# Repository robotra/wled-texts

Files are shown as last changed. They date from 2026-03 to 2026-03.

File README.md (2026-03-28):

# SMS Matrix Display

An ESP32-based scrolling LED matrix display that shows incoming SMS messages fetched from the Twilio API. Configured entirely through a captive-portal web interface — no code changes needed for setup.

---

## Features

- Scrolls the most recent incoming SMS on a 32×8 NeoPixel matrix
- Remembers and restores the last message and text colour across reboots
- Runtime control via SMS commands (text `!color red`, `!speed 200`, `!help`, etc.)
- Settings page accessible at `http://sms-matrix.local/` (mDNS) — no IP address needed
- Settings page protected by HTTP Basic Auth
- Over-the-air firmware updates (no USB cable needed after first flash)
- DST-aware clock via NTP (`!time` is correct year-round)
- Wi-Fi setup via a captive portal (no hardcoded credentials)
- Displays the device IP address on the matrix after connecting
- Twilio SMS polling every 5 seconds on a dedicated core (smooth scrolling, no hitching)
- Optional sender whitelist (allow only specific phone numbers)
- Credential reset via 3 rapid power cycles

---

## Hardware

| Component | Details |
|---|---|
| Microcontroller | ESP32 (e.g. ESP32 DevKit V1) |
| LED Matrix | 32×8 NeoPixel / WS2812B panel |
| Data pin | GPIO 16 → matrix DIN |
| Power | 5V — use a dedicated supply for the matrix at higher brightness |

### Wiring

```
ESP32 GPIO 16  ──►  Matrix DIN
ESP32 GND      ──►  Matrix GND
5V supply      ──►  Matrix VCC + ESP32 VIN
```

> **Note:** The first LED is at the bottom-right corner; rows snake in a zigzag (serpentine) pattern upward. If text appears garbled or mirrored, adjust `MATRIX_TYPE` in `include/config.h`.

---

## Software Dependencies

Built with [PlatformIO](https://platformio.org/) targeting the `esp32dev` board.

| Library | Version |
|---|---|
| Adafruit NeoMatrix | ^1.3.0 |
| Adafruit GFX Library | ^1.11.9 |
| ArduinoJson | ^7.3.0 |

Dependencies are declared in `platformio.ini` and installed automatically by PlatformIO. `ESPmDNS` and `ArduinoOTA` are part of the ESP32 Arduino core — no extra installation needed.

---

## Building & Flashing

1. Install [VS Code](https://code.visualstudio.com/) and the [PlatformIO extension](https://platformio.org/install/ide?install=vscode).
2. Open this folder in VS Code.
3. Click **Build** (✓) to compile, then **Upload** (→) to flash.
4. Open the Serial Monitor at **115200 baud** to see debug output.

After the first USB flash, subsequent firmware updates can be done [over the air](#ota-updates).

---

## First-Time Setup

1. Power on the device for the first time (no credentials stored). The matrix scrolls `SETUP: SMS-Matrix-Setup`.
2. On your phone or laptop, connect to the Wi-Fi network **`SMS-Matrix-Setup`**.
3. A captive portal should open automatically. If not, browse to `http://192.168.4.1`.
4. Fill in the form:
   - **WiFi SSID / Password** — your home/office network
   - **Twilio Account SID** — found in the [Twilio Console](https://console.twilio.com/)
   - **Twilio Auth Token** — found in the Twilio Console
   - **Twilio Phone Number** — the number that receives SMS, in E.164 format (e.g. `+12025551234`)
   - **Allowed Senders** *(optional)* — one E.164 number per line; leave blank to accept messages from anyone
5. Click **Save & Reboot**. The device reboots, connects to Wi-Fi, and scrolls its IP address.

The portal stays open for **5 minutes**. If it closes before you save, power-cycle the device and try again.

> On subsequent boots the portal is skipped and the device connects directly to Wi-Fi. To re-open the portal, perform a [credential reset](#resetting-credentials).

---

## Settings Page

After the initial setup, credentials can be updated at any time without a factory reset by visiting the settings page in a browser:

```
http://sms-matrix.local/
```

If mDNS doesn't work on your network, use the IP address scrolled on the matrix at boot (also printed to Serial Monitor).

The settings page includes a **Timezone** dropdown that auto-detects your location from the browser. Saving a new timezone takes effect immediately for `!time` — no reboot required.

The page is protected by **HTTP Basic Auth**. Default credentials:

| Field | Default |
|---|---|
| Username | `admin` |
| Password | `sms-matrix` |

Change these by editing `WEB_USERNAME` and `WEB_PASSWORD` in `include/config.h` before flashing.

---

## OTA Updates

After the first USB flash, firmware can be updated over WiFi:

**PlatformIO** — add to `platformio.ini`:
```ini
upload_protocol = espota
upload_port = sms-matrix.local
upload_flags = --auth=sms-matrix
```
Then use the normal **Upload** button.

**Arduino IDE** — the device appears under **Tools → Port** as a network port once it's on the same WiFi network. Select it and upload normally; enter `sms-matrix` as the password when prompted.

Change the OTA password by editing `OTA_PASSWORD` in `include/config.h`.

---

## Resetting Credentials

To clear stored Wi-Fi and Twilio credentials and re-open the config portal:

1. Power the device **off**.
2. Power it **on** — wait for the matrix to light up, then immediately power it **off** again (within 3 seconds).
3. Repeat once more (3 power cycles total).

The matrix will scroll **RESET** and the config portal will open.

---

## Twilio Setup

1. Create a free account at [twilio.com](https://www.twilio.com/).
2. Buy or verify a phone number that can receive SMS.
3. Note your **Account SID** and **Auth Token** from the Twilio Console dashboard.
4. Enter these in the config portal as described above.

The device polls the Twilio REST API every 5 seconds and displays the most recent inbound message. It tracks the message SID so the same message is not displayed twice, and persists the SID to flash so a reboot never replays an already-seen message.

Polling runs on **core 0** via a FreeRTOS task, so HTTP latency never interrupts the scroll animation on **core 1**.

---

## SMS Commands

Any message that begins with `!` is treated as a command and is not displayed on the matrix. Commands are subject to the sender whitelist — only permitted numbers can change display settings.

**Persistence:** `!color` is saved to flash and survives a reboot. `!speed` and `!brightness` apply for the current session only — the display always starts at speed 128 and brightness 40 on power-up.

Send `!help` to scroll a summary of all commands on the display.

### `!color <name>`

Changes the text colour. Supported names:

`red` · `green` · `blue` · `white` · `yellow` · `cyan` · `magenta` · `orange` · `purple` · `pink`

```
!color red
!color cyan
```

### `!color <R> <G> <B>`

Sets a custom colour using three space-separated integers (0–255 each).

```
!color 255 128 0
```

### `!speed <1-255>`

Sets the scroll speed for the current session. Higher values are faster. The value maps to a frame delay of `256 − speed` milliseconds. Resets to speed 128 (128 ms/step) on next power-up.

```
!speed 200     ← fast (56 ms/step)
!speed 50      ← slow (206 ms/step)
```

### `!brightness <0-255>`

Sets the LED brightness for the current session. Resets to 40 on next power-up. Keep low (≤80) when powered from USB.

```
!brightness 50
!brightness 200
```

### `!time`

Displays the current date and time, e.g. `Fri Mar 27 09:41 AM`. Requires a WiFi connection for NTP sync. DST is handled automatically via the POSIX timezone rule in `config.h`. The result is not saved — it won't reappear after a reboot.

```
!time
```

> Set your timezone by editing `TZ_POSIX` in `include/config.h`. Common values:
> - Eastern: `"EST5EDT,M3.2.0,M11.1.0"`
> - Central: `"CST6CDT,M3.2.0,M11.1.0"`
> - Mountain: `"MST7MDT,M3.2.0,M11.1.0"`
> - Pacific: `"PST8PDT,M3.2.0,M11.1.0"`

### `!help`

Scrolls a summary of all available commands for 60 seconds, then automatically reverts to the previous message.

```
!help
```

---

## Configuration Reference

All compile-time settings are in [include/config.h](include/config.h).

| Define | Default | Description |
|---|---|---|
| `CONFIG_AP_SSID` | `SMS-Matrix-Setup` | Name of the setup Wi-Fi network |
| `CONFIG_PORTAL_TIMEOUT_MS` | `300000` (5 min) | How long the portal stays open |
| `LED_PIN` | `16` | GPIO pin connected to matrix DIN |
| `MATRIX_WIDTH` | `32` | Number of LED columns |
| `MATRIX_HEIGHT` | `8` | Number of LED rows |
| `LED_BRIGHTNESS` | `20` | Compile-time brightness default (runtime boot value is fixed at 40) |
| `MATRIX_TYPE` | `BOTTOM + RIGHT + COLUMNS + ZIGZAG` | Matrix wiring orientation |
| `TEXT_COLOR_R/G/B` | `255, 255, 255` | Default scroll text colour (white) |
| `SCROLL_DELAY_MS` | `50` | Compile-time scroll delay (runtime boot value is fixed at 128 ms) |
| `POLL_INTERVAL_MS` | `5000` | Milliseconds between Twilio API polls |
| `NTP_SERVER` | `pool.ntp.org` | NTP server for `!time` |
| `TZ_POSIX` | `EST5EDT,...` | POSIX timezone rule (handles DST automatically) |
| `MDNS_HOSTNAME` | `sms-matrix` | mDNS hostname (`sms-matrix.local`) |
| `WEB_USERNAME` | `admin` | Settings page username |
| `WEB_PASSWORD` | `sms-matrix` | Settings page password |
| `OTA_PASSWORD` | `sms-matrix` | OTA firmware update password |

---

## Troubleshooting

| Symptom | Fix |
|---|---|
| Text is upside-down or mirrored | Adjust `MATRIX_TYPE` in `config.h` (try swapping `TOP`/`BOTTOM`, `LEFT`/`RIGHT`, or `ZIGZAG`/`PROGRESSIVE`) |
| Portal doesn't open automatically | Browse manually to `http://192.168.4.1` while connected to `SMS-Matrix-Setup` |
| Device won't connect to Wi-Fi | Reset credentials (3 power cycles) and re-enter them |
| No messages displayed | Check Twilio credentials and ensure messages are sent **to** the configured number |
| Matrix is too dim / too bright | Send `!brightness <value>` or adjust `LED_BRIGHTNESS` in `config.h` (values above ~80 require a dedicated 5V supply) |
| `!color` / `!speed` command ignored | The sending number must be on the whitelist (or the whitelist must be empty) |
| Display shows old message after reboot | Expected — the last non-command message is restored from flash on every boot |
| `sms-matrix.local` not resolving | Use the IP address shown on the matrix at boot; mDNS can be unreliable on some routers |
| OTA upload fails | Ensure the device is on the same WiFi network and the password in `platformio.ini` matches `OTA_PASSWORD` in `config.h` |
| `!time` shows wrong time | Check `TZ_POSIX` in `config.h` matches your timezone |

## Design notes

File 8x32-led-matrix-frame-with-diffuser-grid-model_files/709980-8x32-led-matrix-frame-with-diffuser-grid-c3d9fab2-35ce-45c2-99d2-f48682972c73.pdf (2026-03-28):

## 8x32 LED Matrix Frame with Diffuser

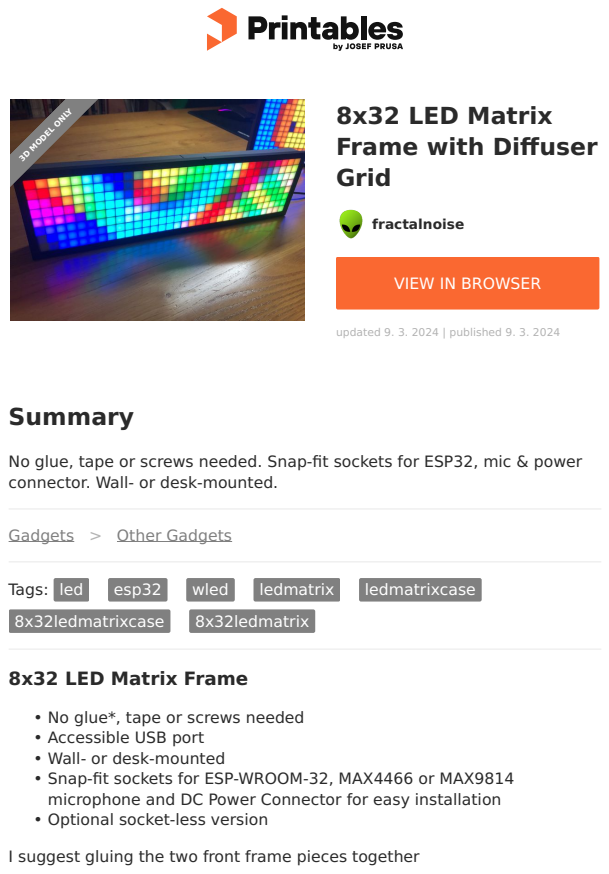
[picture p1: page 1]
Summary; Tags:; led; esp32; wled; ledmatrix; ledmatrixcase; 8x32ledmatrixcase; 8x32ledmatrix; fractalnoise; Grid; updated 9. 3. 2024 | published 9. 3. 2024; 3D MODEL ONLY

VIEW IN BROWSER (https://printables.com/model/709980-8x32-led-matrix-frame-with-diffuser-grid)

No glue, tape or screws needed. Snap-fit sockets for ESP32, mic & power
connector. Wall- or desk-mounted.

Gadgets (https://printables.com/model?categoryId=21) > Other Gadgets (https://printables.com/model?categoryId=43)

8x32 LED Matrix Frame

No glue*, tape or screws needed
Accessible USB port
Wall- or desk-mounted
Snap-fit sockets for ESP-WROOM-32, MAX4466 or MAX9814
microphone and DC Power Connector for easy installation
Optional socket-less version

I suggest gluing the two front frame pieces together

Instructions

Print:

2xFront SPLIT
2xDiffuser SPLIT
1xBackL SPLIT
1xBackR SPLIT

Print the Diffuser Screens with these settings to give the screen a horizontal “scanline” texture:

Top/Bottom surface pattern: ALIGNED RECTILINEAR Internal solid infill pattern: ALIGNED RECTILINEAR
Sparse infill pattern: ALIGNED RECTILINEAR
Infill direction: 0

If using white filament for the Diffuser Screen, printing it on a textured plate will make it scatter more light and be dimmer. Use a smooth plate for best results. A textured plate will work great for clear filament though :)

For the LED matrix, you'll need:

8x32 LED Matrix - e.g. https://aliexpress.com/item/4000544411175.html (https://aliexpress.com/item/4000544411175.html)
ESP-Wroom-32 - e.g. https://aliexpress.com/item/1005005972312714.html (https://aliexpress.com/item/1005005972312714.html)
MAX4466 microphone - e.g. https://aliexpress.com/item/3256803608057399.html (https://aliexpress.com/item/3256803608057399.html)
or
MAX9814 microphone - e.g. https://aliexpress.com/item/3256805923391884.html (https://aliexpress.com/item/3256805923391884.html)
Power Supply 5V 1.5A-15A (~2-5A will do for most uses) - e.g. https://aliexpress.com/item/32844702891.html or https://aliexpress.com/item/1005006126703620.html (https://aliexpress.com/item/1005006126703620.html)
or an old USB cable (cut one end and connect the + and - to the LED matrix)

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
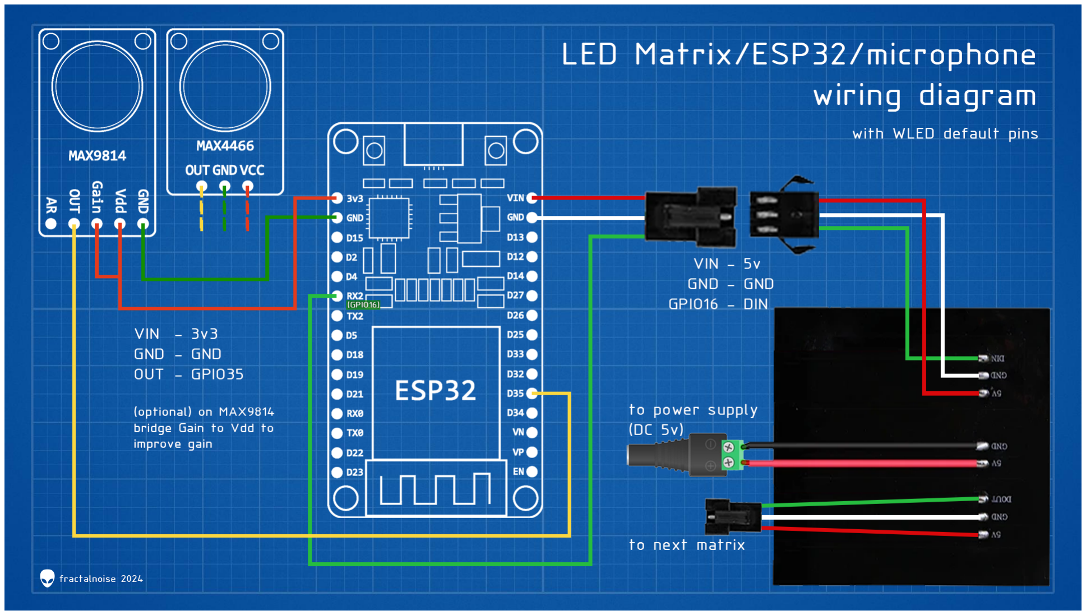
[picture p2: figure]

## Model files

LED Matrix/ESP32/WLED Assembly Guide:

Some useful resources:

WLED Project: https://kno.wled.ge/
Chris Maher WLED tutorials playlist: https://www.youtube.com/playlist?list=PLur8dX5PE-4pk838s_gZAdm-98-sf0f0Z (https://www.youtube.com/playlist?list=PLur8dX5PE-4pk838s_gZAdm-98-sf0f0Z)
Make It Work WLED tutorials playlist: https://www.youtube.com/playlist?list=PLUTKOGJvdIQ8WYfG6TDJ_c8_WlPovWbL9 (https://www.youtube.com/playlist?list=PLUTKOGJvdIQ8WYfG6TDJ_c8_WlPovWbL9)

My other LED projects:

https://www.printables.com/@fractalnoise/collections/1236469

- SPLIT - 3mf | 5 files

•
•

•

8x32-led-matrix-frame-front-split.3mf

- SPLIT - stl | 7 files

8x32-led-matrix-frame-diffuser-split.3mf

8x32-led-matrix-frame-backl-split.3mf

8x32-led-matrix-frame-backl-no-sockets-split.3mf

8x32-led-matrix-frame-backr-split.3mf

8x32-led-matrix-frame-front-split.stl

8x32-led-matrix-frame-diffuser-split.stl

8x32-led-matrix-frame-diffuser_screen-split.stl

8x32-led-matrix-frame-diffuser_grid-split.stl

- WHOLE - 3mf | 4 files
- WHOLE - stl | 6 files

8x32-led-matrix-frame-backl-split.stl

8x32-led-matrix-frame-backl-no-sockets-split.stl

8x32-led-matrix-frame-backr-split.stl

8x32-led-matrix-frame-front-whole.3mf

8x32-led-matrix-frame-diffuser-whole.3mf

8x32-led-matrix-frame-back-whole.3mf

8x32-led-matrix-frame-back-no-sockets-whole.3mf

## License

This work is licensed under a
Creative Commons (4.0 International License)

Attribution—Noncommercial—Share Alike (http://creativecommons.org/licenses/by-nc-sa/4.0/)

✖ | Sharing without ATTRIBUTION
✔ | Remix Culture allowed

8x32-led-matrix-frame-front-whole.stl

8x32-led-matrix-frame-diffuser-whole.stl

8x32-led-matrix-frame-diffuser_screen-whole.stl

8x32-led-matrix-frame-diffuser_grid-whole.stl

8x32-led-matrix-frame-back-whole.stl

8x32-led-matrix-frame-back-no-sockets-whole.stl

8x32-led-matrix-frame.step

✖ | Commercial Use
✖ | Free Cultural Works
✖ | Meets Open Definition

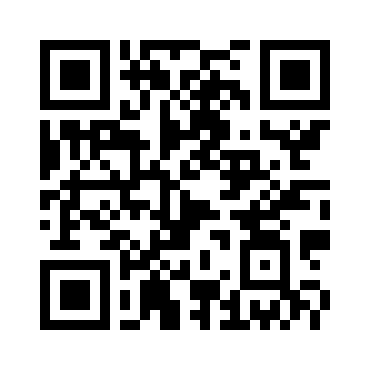
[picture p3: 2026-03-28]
wifi_qr.png

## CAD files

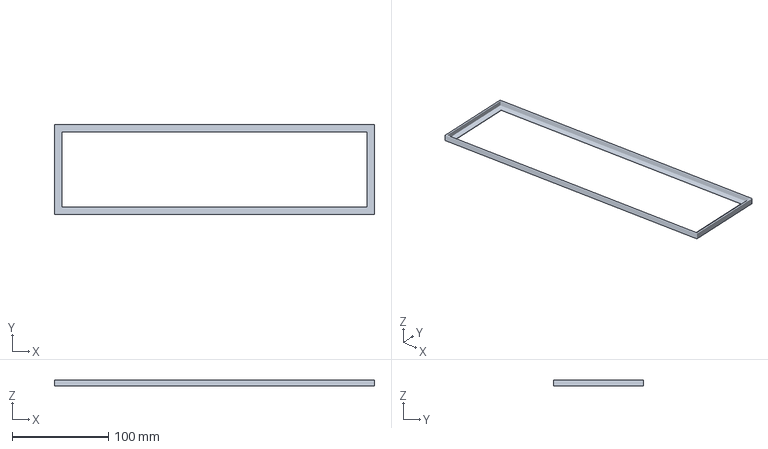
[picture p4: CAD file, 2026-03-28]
8x32-led-matrix-frame-with-diffuser-grid-model_files/WHOLE - 3mf/8x32-led-matrix-frame-front-whole.3mf
333.2 x 93.2 x 6.20 mm

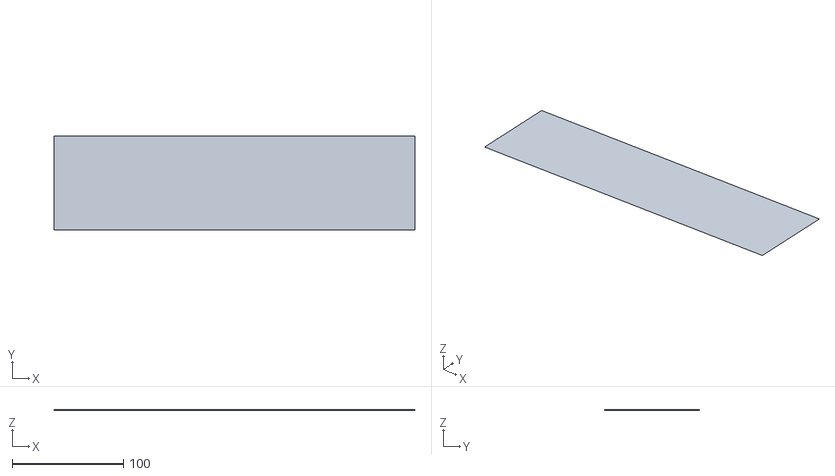
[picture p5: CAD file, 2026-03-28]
8x32-led-matrix-frame-with-diffuser-grid-model_files/WHOLE - stl/8x32-led-matrix-frame-diffuser_screen-whole.stl
325.0 x 85.0 x 0.45

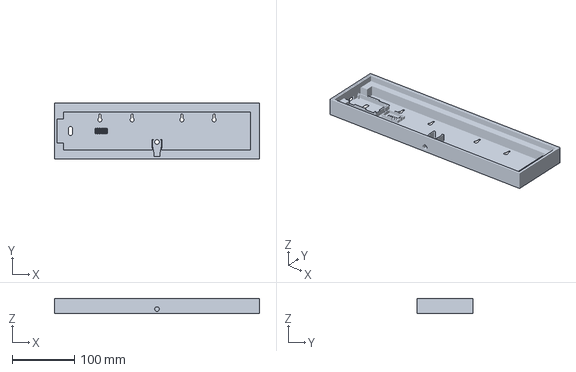
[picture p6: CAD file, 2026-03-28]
8x32-led-matrix-frame-with-diffuser-grid-model_files/WHOLE - 3mf/8x32-led-matrix-frame-back-whole.3mf
330.0 x 90.0 x 24.0 mm

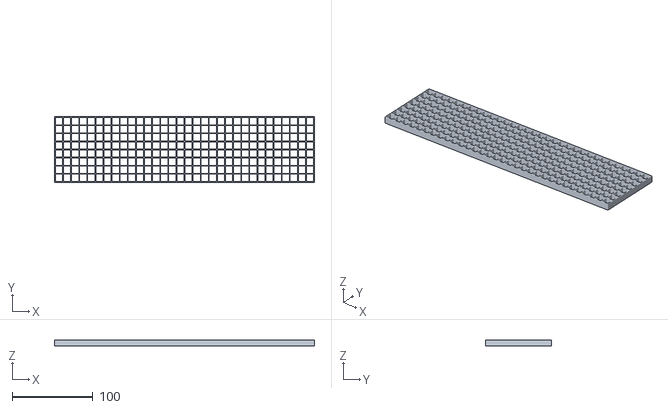
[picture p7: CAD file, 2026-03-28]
8x32-led-matrix-frame-with-diffuser-grid-model_files/WHOLE - stl/8x32-led-matrix-frame-diffuser_grid-whole.stl
321.0 x 81.0 x 8.00

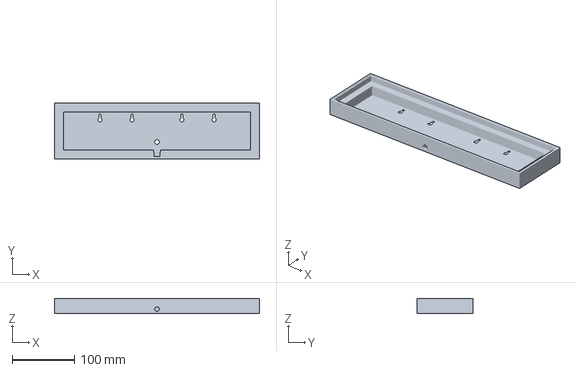
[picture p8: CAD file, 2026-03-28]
8x32-led-matrix-frame-with-diffuser-grid-model_files/WHOLE - 3mf/8x32-led-matrix-frame-back-no-sockets-whole.3mf
330.0 x 90.0 x 24.0 mm

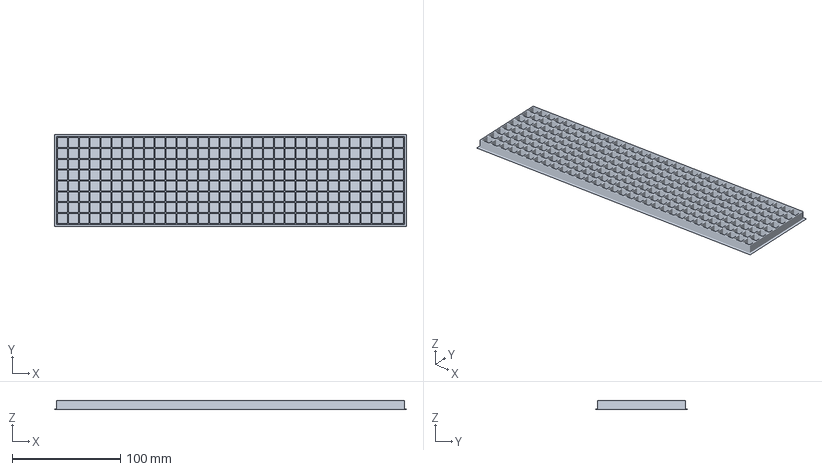
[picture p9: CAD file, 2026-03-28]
8x32-led-matrix-frame-with-diffuser-grid-model_files/WHOLE - 3mf/8x32-led-matrix-frame-diffuser-whole.3mf
325.0 x 85.0 x 8.45 mm

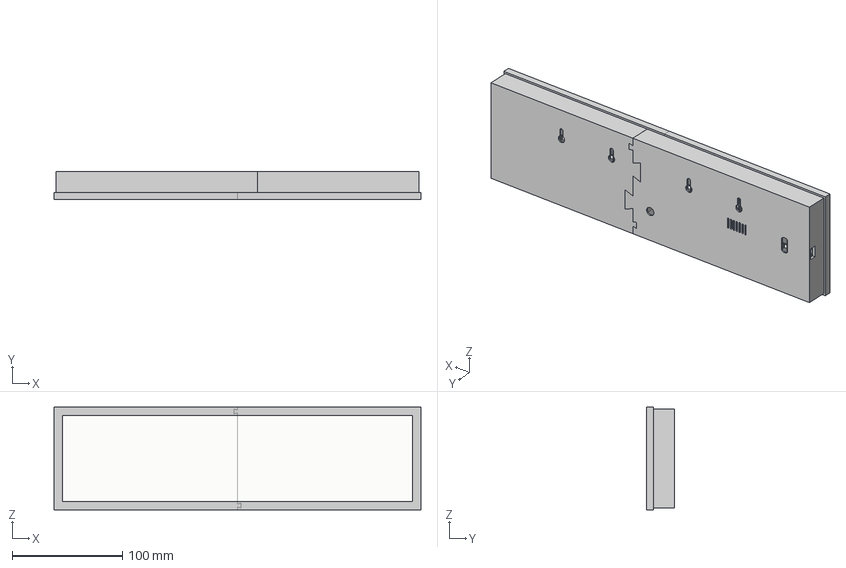
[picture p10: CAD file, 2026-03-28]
8x32-led-matrix-frame-with-diffuser-grid-model_files/8x32-led-matrix-frame.step
333.2 x 25.2 x 93.2 mm
Diffuser
Back
Front

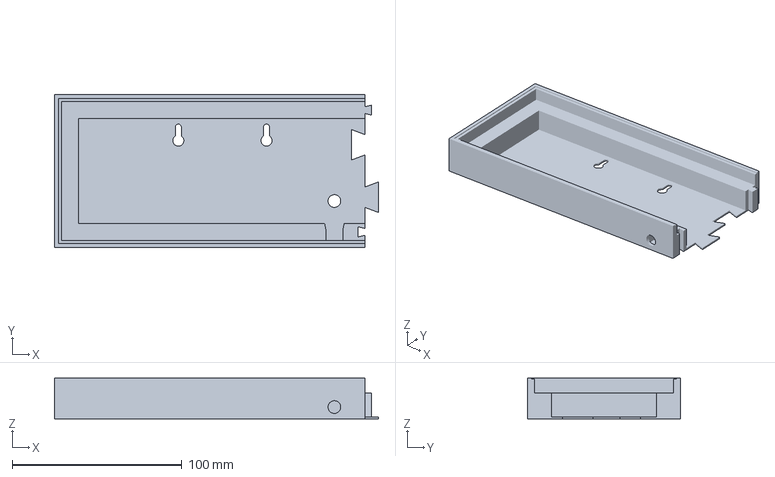
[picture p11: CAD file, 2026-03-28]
8x32-led-matrix-frame-with-diffuser-grid-model_files/SPLIT - 3mf/8x32-led-matrix-frame-backl-no-sockets-split.3mf
191.0 x 90.0 x 24.0 mm

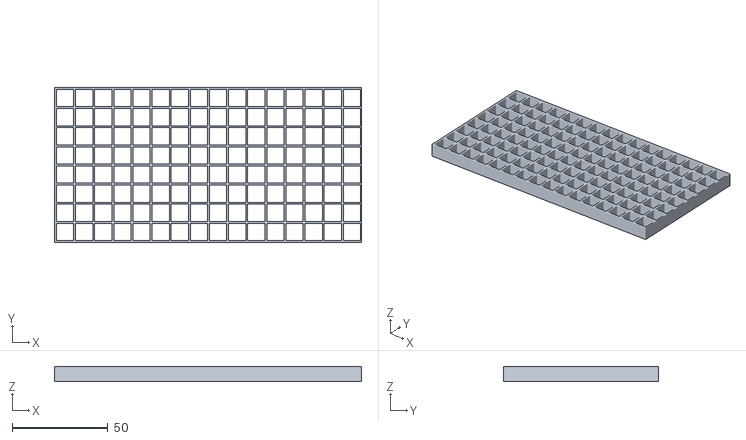
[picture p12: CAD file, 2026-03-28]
8x32-led-matrix-frame-with-diffuser-grid-model_files/SPLIT - stl/8x32-led-matrix-frame-diffuser_grid-split.stl
160.5 x 81.0 x 8.00

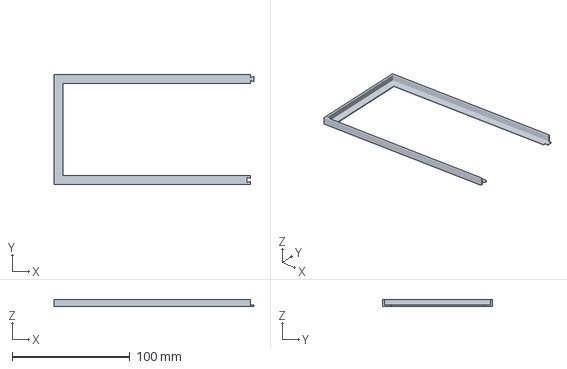
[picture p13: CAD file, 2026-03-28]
8x32-led-matrix-frame-with-diffuser-grid-model_files/SPLIT - 3mf/8x32-led-matrix-frame-front-split.3mf
169.6 x 93.2 x 6.20 mm

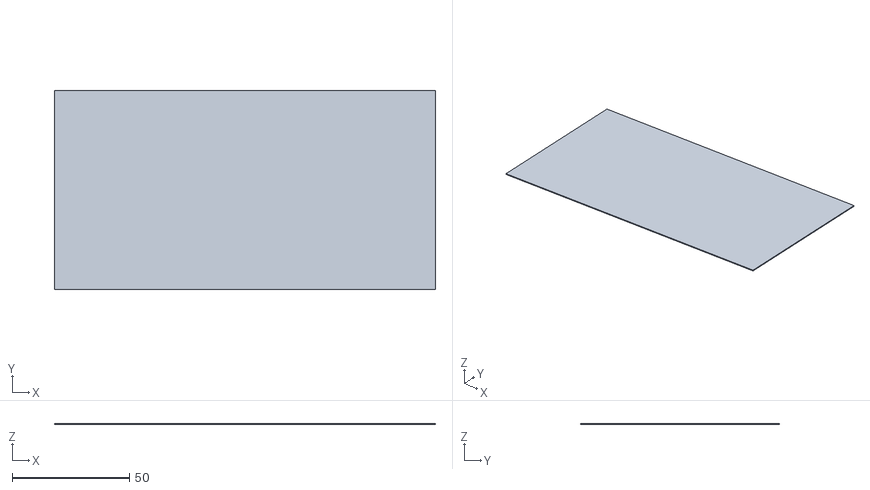
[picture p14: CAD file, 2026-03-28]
8x32-led-matrix-frame-with-diffuser-grid-model_files/SPLIT - stl/8x32-led-matrix-frame-diffuser_screen-split.stl
162.5 x 85.0 x 0.45

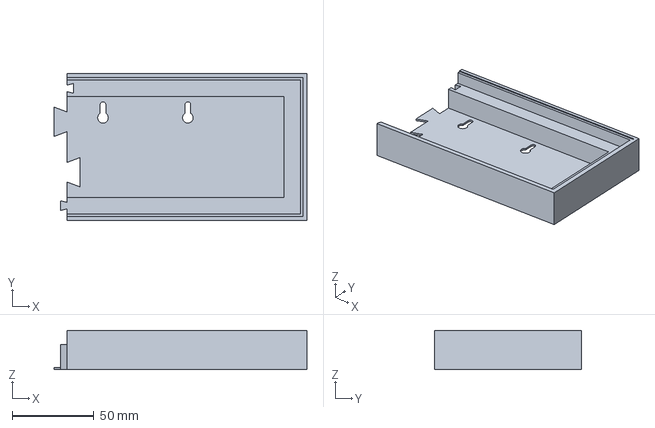
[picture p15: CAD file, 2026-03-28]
8x32-led-matrix-frame-with-diffuser-grid-model_files/SPLIT - 3mf/8x32-led-matrix-frame-backr-split.3mf
155.0 x 90.0 x 24.0 mm

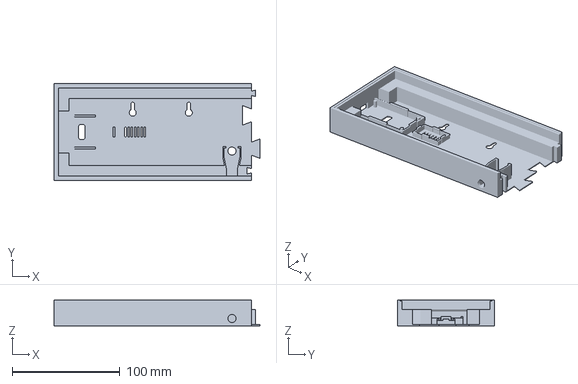
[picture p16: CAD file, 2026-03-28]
8x32-led-matrix-frame-with-diffuser-grid-model_files/SPLIT - 3mf/8x32-led-matrix-frame-backl-split.3mf
191.0 x 90.0 x 24.0 mm

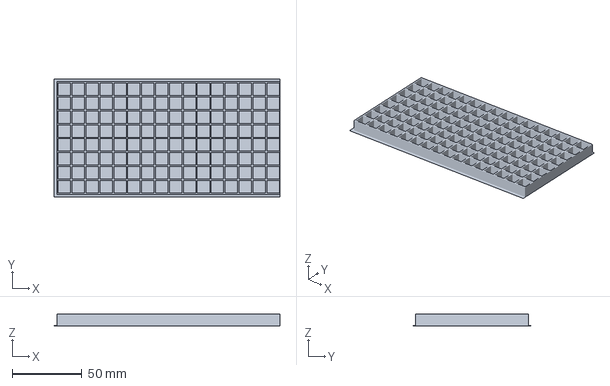
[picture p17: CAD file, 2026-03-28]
8x32-led-matrix-frame-with-diffuser-grid-model_files/SPLIT - 3mf/8x32-led-matrix-frame-diffuser-split.3mf
162.5 x 85.0 x 8.45 mm

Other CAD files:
8x32-led-matrix-frame-with-diffuser-grid-model_files/SPLIT - stl/8x32-led-matrix-frame-backl-no-sockets-split.stl
8x32-led-matrix-frame-with-diffuser-grid-model_files/SPLIT - stl/8x32-led-matrix-frame-backl-split.stl
8x32-led-matrix-frame-with-diffuser-grid-model_files/SPLIT - stl/8x32-led-matrix-frame-backr-split.stl
8x32-led-matrix-frame-with-diffuser-grid-model_files/SPLIT - stl/8x32-led-matrix-frame-diffuser-split.stl
8x32-led-matrix-frame-with-diffuser-grid-model_files/SPLIT - stl/8x32-led-matrix-frame-front-split.stl
8x32-led-matrix-frame-with-diffuser-grid-model_files/WHOLE - stl/8x32-led-matrix-frame-back-no-sockets-whole.stl
8x32-led-matrix-frame-with-diffuser-grid-model_files/WHOLE - stl/8x32-led-matrix-frame-back-whole.stl
8x32-led-matrix-frame-with-diffuser-grid-model_files/WHOLE - stl/8x32-led-matrix-frame-diffuser-whole.stl
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

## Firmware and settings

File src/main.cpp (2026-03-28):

// =============================================================================
//  SMS Matrix — main.cpp
//
//  Scrolls the most-recent inbound Twilio SMS across an 8×32 NeoPixel matrix.
//
//  Boot flow
//  ---------
//  1. Power on → matrix initialised, NVS opened.
//  2. If the device has been power-cycled 3 times in quick succession the NVS
//     is wiped and the config portal opens so the user can re-enter credentials.
//  3. If no WiFi SSID is stored the config portal opens automatically.
//  4. Config is loaded from NVS, the device connects to WiFi in station mode.
//  5. NTP sync begins; timezone (POSIX string) is loaded from NVS so DST is
//     handled automatically for !time.
//  6. Settings web server starts on port 80 (HTTP Basic Auth protected).
//     mDNS advertises the device as http://sms-matrix.local/.
//  7. ArduinoOTA is started so firmware can be updated over WiFi.
//  8. A background FreeRTOS task (core 0) polls the Twilio REST API every
//     POLL_INTERVAL_MS milliseconds.
//  9. loop() runs on core 1, servicing OTA, the web server, pending display
//     changes, the !help expiry timer, and the scroll animation.
//
//  Inter-task synchronisation
//  --------------------------
//  The poll task and loop() share `pendingMessage` / `hasPendingMessage`.
//  `msgMutex` ensures the loop() never reads a partially-written string.
// =============================================================================

#include <Arduino.h>
#include <WiFi.h>              // WiFi station + soft-AP
#include <WebServer.h>         // Tiny HTTP server used by the config portal
#include <HTTPClient.h>        // Outbound HTTP(S) requests to Twilio
#include <WiFiClientSecure.h>  // TLS-capable TCP socket (used with HTTPClient)
#include <Preferences.h>       // Arduino wrapper around ESP32 NVS (flash KV store)
#include <ArduinoJson.h>       // Deserialises the Twilio JSON response
#include <Adafruit_NeoMatrix.h>// High-level text/graphics on NeoPixel matrices
#include <Adafruit_GFX.h>      // Base graphics library required by NeoMatrix
#include <ESPmDNS.h>           // mDNS — advertises the device as sms-matrix.local
#include <ArduinoOTA.h>        // Over-the-air firmware updates over WiFi
#include "config.h"            // Hardware pin / timing constants (no secrets)

// =============================================================================
//  Matrix object
//  The constructor arguments describe the physical layout; change MATRIX_TYPE
//  in config.h if the text appears mirrored, upside-down, or in the wrong order.
// =============================================================================
Adafruit_NeoMatrix matrix(
    MATRIX_WIDTH,   // number of pixels across
    MATRIX_HEIGHT,  // number of pixels tall
    LED_PIN,        // GPIO connected to the data-in pin of the first pixel
    MATRIX_TYPE,    // wiring topology (progressive / zigzag, origin corner, etc.)
    NEO_GRB + NEO_KHZ800  // colour order and signal frequency — standard WS2812B
);

// =============================================================================
//  Runtime config — loaded from NVS at boot via loadConfig().
//  Never hard-code credentials here; they are entered through the web portal.
// =============================================================================
struct Config {
    String ssid;          // WiFi network name
    String pass;          // WiFi password (may be empty for open networks)
    String twilioSid;     // Twilio Account SID  (starts with "AC…")
    String twilioToken;   // Twilio Auth Token
    String twilioNumber;  // E.164 number that receives SMS (e.g. "+15550001234")
    String whitelist;     // Newline-separated E.164 senders; empty = allow all
};

Config      cfg;          // Global config populated by loadConfig()
Preferences prefs;        // NVS handle — kept open for the lifetime of the sketch
WebServer   server(80);   // HTTP server instance used only during the config portal

// =============================================================================
//  Scrolling state
//  All access to these from loop() only — no locking needed.
// =============================================================================

// The text currently being scrolled across the matrix.
String currentMessage = "Waiting for SMS...";

// Twilio message SID of the last message we displayed.
// Used to detect when a genuinely new message has arrived.
String lastSeenSid = "";

// Horizontal cursor position for the scroll animation.
// Starts at MATRIX_WIDTH (just off the right edge) and decrements each tick.
int scrollX = MATRIX_WIDTH;

// Timestamp (millis()) of the last scroll step — used for non-blocking timing.
unsigned long lastScrollTime = 0;

// When non-zero, millis() timestamp at which to revert from the !help text back
// to the previous message.  Set by !help, checked in loop().
unsigned long helpExpiresAt  = 0;
String        preHelpMessage = "";  // Message to restore when help expires

// =============================================================================
//  Inter-task message handoff (poll task → loop)
//
//  The poll task writes pendingMessage + sets hasPendingMessage = true while
//  holding msgMutex.  loop() picks it up with a non-blocking tryTake so it
//  never stalls the animation.
// =============================================================================
SemaphoreHandle_t msgMutex;                    // Binary mutex protecting the fields below
String            pendingMessage    = "";       // Latest SMS body from the poll task
volatile bool     hasPendingMessage = false;   // Written core 0, read core 1 — must be volatile

// Pending colour change (written by poll task, applied by loop() via matrix.setTextColor)
volatile bool hasPendingColor = false;         // Written core 0, read core 1 — must be volatile
uint8_t pendingColorR   = TEXT_COLOR_R;
uint8_t pendingColorG   = TEXT_COLOR_G;
uint8_t pendingColorB   = TEXT_COLOR_B;

// Pending scroll-speed change.  Speed 1–255: higher = faster.
// Stored internally as a delay (ms): delay = 256 - speed.
// Reset to 128 ms on every boot regardless of last !speed command.
volatile bool hasPendingSpeed    = false;      // Written core 0, read core 1 — must be volatile
unsigned long pendingScrollDelay = 128;
unsigned long currentScrollDelay = 128;        // Active delay used by loop(); fixed at boot

// Pending brightness change.
// Reset to 40 on every boot regardless of last !brightness command.
volatile bool hasPendingBrightness = false;    // Written core 0, read core 1 — must be volatile
uint8_t       pendingBrightness    = 40;

// =============================================================================
//  Config portal HTML
//
//  Stored in flash (PROGMEM) rather than SRAM to save precious heap space.
//  Placeholder tokens ({{SSID}}, etc.) are replaced at request time with
//  the current NVS values so the form is pre-filled on revisits.
//
//  The countdown script in the page mirrors CONFIG_PORTAL_TIMEOUT_MS (300 s).
// =============================================================================
static const char CONFIG_HTML[] PROGMEM = R"rawliteral(
<!DOCTYPE html><html>
<head>
  <title>SMS Matrix Setup</title>
  <meta name="viewport" content="width=device-width,initial-scale=1">
  <style>
    *{box-sizing:border-box}
    body{font-family:sans-serif;max-width:420px;margin:30px auto;padding:0 16px;background:#111;color:#eee}
    h1{color:#4fc3f7;margin-bottom:4px}
    p{color:#888;font-size:13px;margin-top:0}
    label{display:block;font-size:13px;margin:12px 0 4px;color:#aaa}
    input,textarea,select{width:100%;padding:9px 10px;border:1px solid #333;background:#222;color:#eee;border-radius:4px;font-size:14px}
    input:focus,textarea:focus,select:focus{border-color:#4fc3f7;outline:none}
    textarea{height:90px;resize:vertical;font-family:monospace}
    button{margin-top:20px;width:100%;padding:12px;background:#4fc3f7;color:#111;border:none;border-radius:4px;font-size:15px;font-weight:bold;cursor:pointer}
    .note{color:#f57c00;font-size:13px;margin-top:14px;text-align:center}
  </style>
</head>
<body>
  <h1>SMS Matrix Setup</h1>
  <p>Connect to <b>SMS-Matrix-Setup</b>, fill in the form, and save before the 5-minute window closes.</p>
  <form method="POST" action="/save">
    <label>WiFi SSID</label>
    <input name="ssid" type="text" value="{{SSID}}" required autocomplete="off">
    <label>WiFi Password</label>
    <input name="pass" type="password" value="{{PASS}}" autocomplete="off">
    <label>Twilio Account SID</label>
    <input name="sid" type="text" value="{{SID}}" required autocomplete="off" placeholder="ACxxxxxxxxxxxxxxxxxxxxxxxxxxxxxxxx">
    <label>Twilio Auth Token</label>
    <input name="token" type="password" value="{{TOKEN}}" required autocomplete="off">
    <label>Twilio Phone Number</label>
    <input name="number" type="tel" value="{{NUMBER}}" required placeholder="+1xxxxxxxxxx">
    <label>Allowed Senders (one number per line, E.164 format)</label>
    <textarea name="whitelist" placeholder="+12025551234&#10;+14155559876&#10;&#10;Leave empty to allow everyone.">{{WHITELIST}}</textarea>
    <label>Timezone</label>
    <select name="tz" id="tzsel">
      <option value="EST5EDT,M3.2.0,M11.1.0">Eastern (EST/EDT)</option>
      <option value="CST6CDT,M3.2.0,M11.1.0">Central (CST/CDT)</option>
      <option value="MST7MDT,M3.2.0,M11.1.0">Mountain (MST/MDT)</option>
      <option value="MST7">Mountain – Arizona (no DST)</option>
      <option value="PST8PDT,M3.2.0,M11.1.0">Pacific (PST/PDT)</option>
      <option value="AKST9AKDT,M3.2.0,M11.1.0">Alaska (AKST/AKDT)</option>
      <option value="HST10">Hawaii (HST)</option>
      <option value="UTC0">UTC</option>
    </select>
    <button type="submit">Save &amp; Reboot</button>
  </form>
  <div class="note">Portal closes in <span id="t">300</span>s</div>
  <script>
    var s=300,iv=setInterval(function(){document.getElementById('t').textContent=--s;if(s<=0)clearInterval(iv)},1000);
    // Pre-select stored timezone, or auto-detect from browser if none stored
    (function(){
      var stored="{{TZ}}";
      var ianaMap={
        'America/New_York':'EST5EDT,M3.2.0,M11.1.0',
        'America/Detroit':'EST5EDT,M3.2.0,M11.1.0',
        'America/Indiana/Indianapolis':'EST5EDT,M3.2.0,M11.1.0',
        'America/Chicago':'CST6CDT,M3.2.0,M11.1.0',
        'America/Denver':'MST7MDT,M3.2.0,M11.1.0',
        'America/Phoenix':'MST7',
        'America/Los_Angeles':'PST8PDT,M3.2.0,M11.1.0',
        'America/Anchorage':'AKST9AKDT,M3.2.0,M11.1.0',
        'Pacific/Honolulu':'HST10'
      };
      var val=stored||ianaMap[Intl.DateTimeFormat().resolvedOptions().timeZone]||'';
      var sel=document.getElementById('tzsel');
      for(var i=0;i<sel.options.length;i++){
        if(sel.options[i].value===val){sel.selectedIndex=i;break;}
      }
    })();
  </script>
</body></html>
)rawliteral";

// =============================================================================
//  requireAuth()
//
//  Checks HTTP Basic Auth credentials against WEB_USERNAME / WEB_PASSWORD from
//  config.h.  Call at the top of any handler that should be protected.
//  Returns true if authenticated; false if a 401 challenge was sent (the caller
//  must return immediately without sending another response).
// =============================================================================
bool requireAuth() {
    if (!server.authenticate(WEB_USERNAME, WEB_PASSWORD)) {
        server.requestAuthentication(BASIC_AUTH, "SMS Matrix");
        return false;
    }
    return true;
}

// =============================================================================
//  handleRoot()
//
//  Serves the setup form at GET /.
//  Reads the current NVS values so the form is pre-filled — except passwords,
//  which are intentionally left blank for security.
// =============================================================================
void handleRoot() {
    if (!requireAuth()) return;

    // Copy HTML from flash to a RAM String so we can do replacements on it
    String html = FPSTR(CONFIG_HTML);

    // Substitute each placeholder with the matching stored value.
    // Passwords are shown as empty strings — the user must re-enter them.
    html.replace("{{SSID}}",      prefs.getString("ssid",      ""));
    html.replace("{{PASS}}",      prefs.getString("pass",      ""));  // intentionally blank
    html.replace("{{SID}}",       prefs.getString("tw_sid",    ""));
    html.replace("{{TOKEN}}",     prefs.getString("tw_token",  ""));  // intentionally blank
    html.replace("{{NUMBER}}",    prefs.getString("tw_num",    ""));
    html.replace("{{WHITELIST}}", prefs.getString("whitelist", ""));
    html.replace("{{TZ}}",        prefs.getString("tz_posix",  ""));

    server.send(200, "text/html", html);
}

// =============================================================================
//  handleSave()
//
//  Receives the POST from the setup form, persists each field to NVS, sends an
//  acknowledgment page, then restarts the ESP32 so it boots into normal mode.
//
//  The whitelist is normalised: Windows-style CRLF line endings are converted
//  to LF, and leading/trailing whitespace is stripped before storing.
// =============================================================================
void handleSave() {
    if (!requireAuth()) return;

    // Persist each submitted field; hasArg guards against missing form fields.
    if (server.hasArg("ssid"))   prefs.putString("ssid",     server.arg("ssid"));
    if (server.hasArg("pass"))   prefs.putString("pass",     server.arg("pass"));
    if (server.hasArg("sid"))    prefs.putString("tw_sid",   server.arg("sid"));
    if (server.hasArg("token"))  prefs.putString("tw_token", server.arg("token"));
    if (server.hasArg("number")) prefs.putString("tw_num",   server.arg("number"));
    if (server.hasArg("tz")) {
        String tz = server.arg("tz");
        prefs.putString("tz_posix", tz);
        // Apply immediately so !time reflects the new zone without waiting for reboot
        setenv("TZ", tz.c_str(), 1);
        tzset();
    }

    if (server.hasArg("whitelist")) {
        String wl = server.arg("whitelist");
        // Normalise line endings so the whitelist looks the same regardless of
        // which OS the user's browser is running on.
        wl.replace("\r\n", "\n");  // Windows CRLF → LF
        wl.replace("\r", "\n");    // Old Mac CR  → LF
        wl.trim();                  // Remove surrounding blank lines / spaces
        prefs.putString("whitelist", wl);
    }

    // Acknowledge the save before restarting so the browser receives the reply.
    server.send(200, "text/html",
        "<html><body style='background:#111;color:#4fc3f7;font-family:sans-serif;"
        "padding:40px;text-align:center'><h2>Saved! Rebooting...</h2></body></html>");

    delay(1500);      // Give the browser time to render the response
    ESP.restart();    // Full reset; device will boot into normal (non-portal) mode
}

// =============================================================================
//  handleRedirect()
//
//  Catches the automatic "captive portal detection" probes that Android and iOS
//  send when joining an unknown WiFi network and redirects them to the setup
//  page.  Without this, phones may show "No internet — tap to sign in" but then
//  fail to open the portal automatically.
//
//  Known probe URLs:
//    Android : GET /generate_204
//    iOS/macOS: GET /hotspot-detect.html
// =============================================================================
void handleRedirect() {
    server.sendHeader("Location", "http://192.168.4.1/", true);  // absolute URL required
    server.send(302, "text/plain", "");
}

// =============================================================================
//  runConfigPortal()
//
//  Brings up a WiFi soft-AP and serves the setup form until the user submits
//  valid credentials or until CONFIG_PORTAL_TIMEOUT_MS elapses.
//
//  The matrix keeps scrolling while the portal runs so the user can see the
//  AP name and knows the device is waiting.  handleSave() calls ESP.restart()
//  on success, so this function only returns on timeout.
// =============================================================================
void runConfigPortal() {
    // Show the AP name on the matrix so the user knows what to connect to
    currentMessage = String("SETUP: ") + CONFIG_AP_SSID;
    scrollX = MATRIX_WIDTH;  // Reset scroll so the message starts from the right

    // Bring up the soft-AP.  No password = open network, easier for first setup.
    WiFi.mode(WIFI_AP);
    WiFi.softAP(CONFIG_AP_SSID);
    Serial.println("Config AP started. Connect to: " + String(CONFIG_AP_SSID));
    Serial.println("Portal URL: http://" + WiFi.softAPIP().toString() + "/");

    // Register URL routes
    server.on("/",                    HTTP_GET,  handleRoot);
    server.on("/save",                HTTP_POST, handleSave);
    server.on("/generate_204",        HTTP_GET,  handleRedirect);  // Android captive probe
    server.on("/hotspot-detect.html", HTTP_GET,  handleRedirect);  // iOS captive probe
    server.onNotFound(handleRedirect);  // Catch all other URLs → redirect to portal
    server.begin();

    unsigned long portalStart = millis();

    // Service loop — runs until the portal times out (handleSave restarts early)
    while (millis() - portalStart < CONFIG_PORTAL_TIMEOUT_MS) {
        server.handleClient();  // Process any pending HTTP request

        // Non-blocking scroll animation — identical logic to the normal loop()
        unsigned long now = millis();
        if (now - lastScrollTime >= SCROLL_DELAY_MS) {
            lastScrollTime = now;

            matrix.fillScreen(0);            // Clear all pixels
            matrix.setCursor(scrollX, 1);    // Y=1 centres 7px-tall text in 8 rows
            matrix.print(currentMessage);
            matrix.show();                   // Push pixel data to the strip

            scrollX--;
            // Each character is 6 px wide (5 px glyph + 1 px gap)
            int textPixelWidth = (int)currentMessage.length() * 6;
            // Once the text has fully scrolled off the left edge, reset to the right
            if (scrollX < -textPixelWidth) scrollX = MATRIX_WIDTH;
        }
    }

    // Timeout reached — clean up and return so the caller can decide what to do
    server.stop();
    WiFi.softAPdisconnect(true);  // true = also disable the radio
    Serial.println("Config portal closed, resuming normal boot.");
}

// =============================================================================
//  loadConfig()
//
//  Reads all credential fields from NVS into the global `cfg` struct.
//  Called once after the config portal check in setup().
//  Empty strings are the default so missing keys fail gracefully.
// =============================================================================
void loadConfig() {
    cfg.ssid         = prefs.getString("ssid",      "");
    cfg.pass         = prefs.getString("pass",      "");
    cfg.twilioSid    = prefs.getString("tw_sid",    "");
    cfg.twilioToken  = prefs.getString("tw_token",  "");
    cfg.twilioNumber = prefs.getString("tw_num",    "");
    cfg.whitelist    = prefs.getString("whitelist", "");
}
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
void loop() {
    // ---- Service OTA and the settings web server ----------------------------
    ArduinoOTA.handle();
    server.handleClient();

    // ---- !help expiry — revert to previous message after 60 seconds ---------
    if (helpExpiresAt != 0 && millis() >= helpExpiresAt) {
        helpExpiresAt  = 0;
        currentMessage = preHelpMessage;
        scrollX        = MATRIX_WIDTH;
    }

    // ---- Check for a new message from the poll task -------------------------
    if (hasPendingMessage) {
        // Non-blocking: if the mutex isn't available right now, skip and try
        // next iteration rather than stalling the animation.
        if (xSemaphoreTake(msgMutex, 0)) {
            currentMessage    = pendingMessage;  // Replace the displayed text
            scrollX           = MATRIX_WIDTH;    // Restart scroll from the right edge
            hasPendingMessage = false;           // Acknowledge the handoff
            helpExpiresAt     = 0;              // Cancel any active !help timer
            xSemaphoreGive(msgMutex);
        }
    }

    // ---- Apply pending colour change ----------------------------------------
    if (hasPendingColor) {
        if (xSemaphoreTake(msgMutex, 0)) {
            matrix.setTextColor(matrix.Color(pendingColorR, pendingColorG, pendingColorB));
            hasPendingColor = false;
            xSemaphoreGive(msgMutex);
        }
    }

    // ---- Apply pending speed change -----------------------------------------
    if (hasPendingSpeed) {
        if (xSemaphoreTake(msgMutex, 0)) {
            currentScrollDelay = pendingScrollDelay;
            hasPendingSpeed    = false;
            xSemaphoreGive(msgMutex);
        }
    }

    // ---- Apply pending brightness change ------------------------------------
    if (hasPendingBrightness) {
        if (xSemaphoreTake(msgMutex, 0)) {
            matrix.setBrightness(pendingBrightness);
            hasPendingBrightness = false;
            xSemaphoreGive(msgMutex);
        }
    }

    // ---- Non-blocking scroll timer ------------------------------------------
    unsigned long now = millis();
    if (now - lastScrollTime >= currentScrollDelay) {
        lastScrollTime = now;
        scrollTick();  // Advance one pixel and redraw
    }
}

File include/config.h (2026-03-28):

#pragma once

// ── Config portal ─────────────────────────────────────────────────────────────
#define CONFIG_AP_SSID            "SMS-Matrix-Setup"  // AP name shown on devices
#define CONFIG_PORTAL_TIMEOUT_MS  300000              // portal window (ms)

// ── LED Matrix ────────────────────────────────────────────────────────────────
#define LED_PIN         16     // GPIO pin connected to matrix DIN
#define MATRIX_WIDTH    32
#define MATRIX_HEIGHT   8
#define LED_BRIGHTNESS  20    // 0-255; keep low when powering from USB

// Matrix wiring layout — adjust if text appears garbled:
//   NEO_MATRIX_ZIGZAG      = serpentine (most common for hand-wired panels)
//   NEO_MATRIX_PROGRESSIVE = all rows left-to-right (common on pre-made panels)
#define MATRIX_TYPE  (NEO_MATRIX_TOP + NEO_MATRIX_LEFT + \
                      NEO_MATRIX_COLUMNS + NEO_MATRIX_ZIGZAG)

// ── NTP / time ────────────────────────────────────────────────────────────────
#define NTP_SERVER  "pool.ntp.org"
// POSIX timezone string — handles DST automatically.
// Common US values:
//   Eastern : "EST5EDT,M3.2.0,M11.1.0"
//   Central : "CST6CDT,M3.2.0,M11.1.0"
//   Mountain: "MST7MDT,M3.2.0,M11.1.0"
//   Pacific : "PST8PDT,M3.2.0,M11.1.0"
#define TZ_POSIX  "EST5EDT,M3.2.0,M11.1.0"

// ── Network services ──────────────────────────────────────────────────────────
// mDNS hostname — device will be reachable at http://<MDNS_HOSTNAME>.local/
#define MDNS_HOSTNAME  "sms-matrix"

// Settings web server credentials (HTTP Basic Auth)
#define WEB_USERNAME  "admin"
#define WEB_PASSWORD  "sms-matrix"

// OTA update password (use Arduino IDE / PlatformIO OTA upload)
#define OTA_PASSWORD  "sms-matrix"

// ── Text / scroll ─────────────────────────────────────────────────────────────
#define TEXT_COLOR_R    255
#define TEXT_COLOR_G    255
#define TEXT_COLOR_B    255

#define SCROLL_DELAY_MS   50    // ms between scroll steps (lower = faster)
#define POLL_INTERVAL_MS  5000  // ms between Twilio API polls
